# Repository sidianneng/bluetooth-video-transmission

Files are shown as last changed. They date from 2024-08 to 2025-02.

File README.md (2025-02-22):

# 蓝牙图像传输 | [Ble video transmission](./README-EN.md)
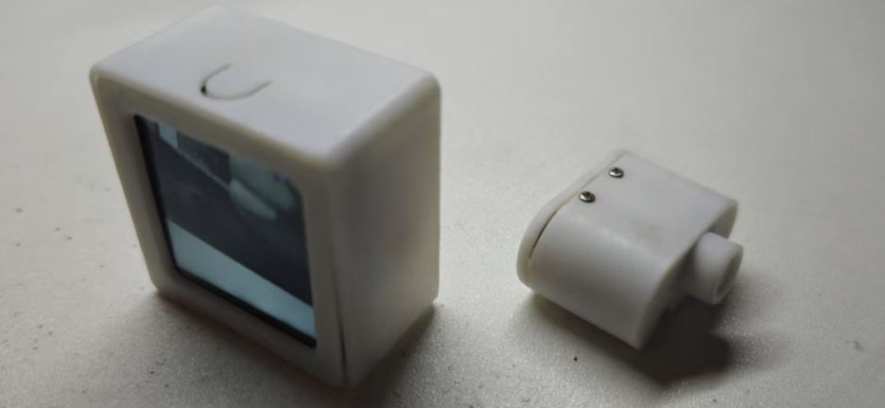
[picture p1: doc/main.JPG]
ble_video_tranmission


## 1 项目概述
现实应用中，无线视频传输一般使用的是带宽比较大的WIFI来实现，那么对于带宽非常有限的蓝牙来说是否有传输视频的可能性。其实23年上市的insta 360 go3已经给了我们答案：这个想法是可行的。
受insta 360 go3的启发，我开始了这个项目。本项目基于ESP32-S3实现。传输图像分辨率为240x240。

## 2 功能介绍
### 2.1 发送端
* 系统启动后初始化摄像头和开启ble gatt server
* 按下按键后指示灯开始显示工作状态
* 指示灯有红绿蓝三种颜色，其中绿色表示电量高，蓝色表示电量中等，红色表示电量低
* 指示灯慢闪表示发送端蓝牙没有被连接，快闪表示已经被连接了
* 再次按下按键后关闭指示灯
* 发送端放到充电仓中后会常亮显示表示正在充电(此时无法通过按键熄灭)

### 2.2 接收端
* 系统启动后会初始化屏幕和自动搜索ble gatt server
* 搜索到server后会自动连接和接收图像数据
* 按下按键后会开启屏幕背光，显示画面
* 屏幕右上角有电池图标显示电量
* 接入充电线后电池图标会显示正在充电中

## 3 原理解析
* 蓝牙的传输基于GATT的NOTIFY实现，最大传输速度在90KB/s左右
* 摄像头使用的OV2640，在图像格式配置为JPEG，分辨率为240x240
* JPEG解码库使用的esp_jpeg

### 如果对本项目有任何疑问，欢迎在issue中与我讨论。

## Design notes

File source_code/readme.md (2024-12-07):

# Video data packet definition

* packet header 1byte
* current frame count 1byte
* current total packet count 1bytes
* current current packet count 1bytes
* current packet length 2bytes
* packet data nbytes

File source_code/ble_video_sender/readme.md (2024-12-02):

# How to build this code

`idf.py set-target esp32s3`

`idf.py add-dependency "espressif/esp32-camera"`

`idf.py build`

`idf.py -p /dev/ttyxxx flash monitor`

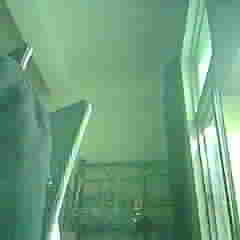
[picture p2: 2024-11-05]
source_code/ble_video_receiver/main/image.jpg

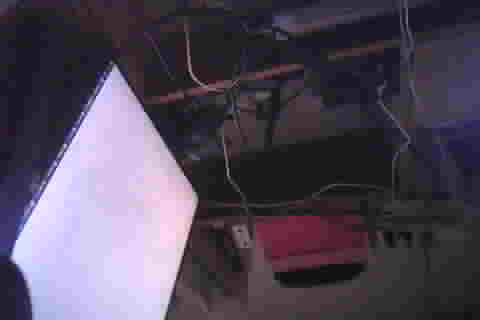
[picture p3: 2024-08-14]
tools/output.jpg

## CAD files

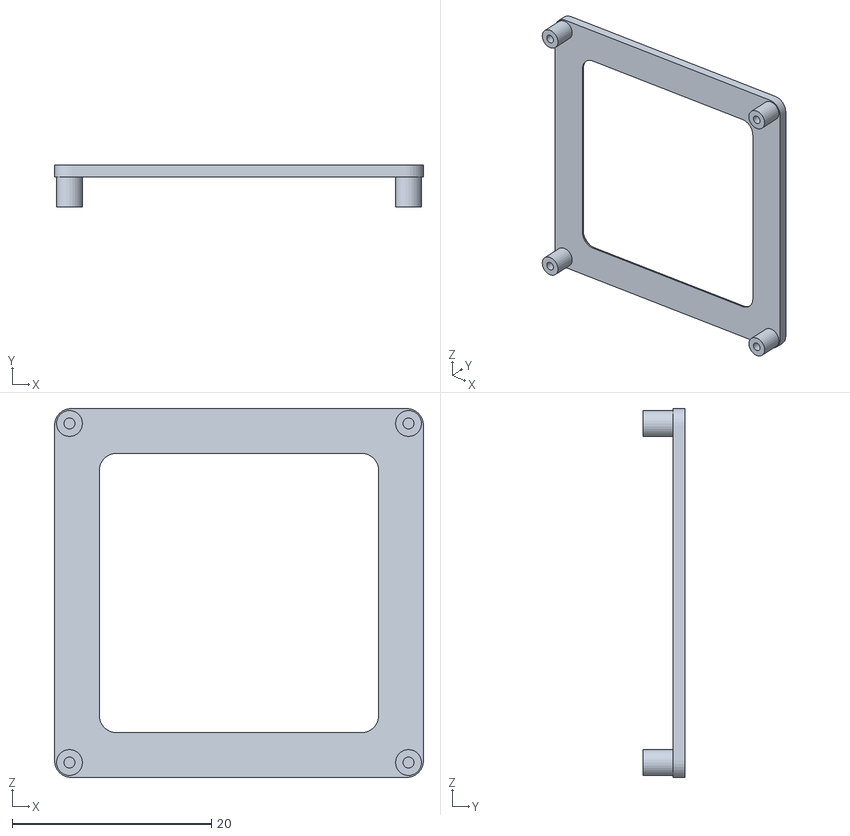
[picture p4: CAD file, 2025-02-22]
3d-modules/receiver-v7.stl
37.0 x 4.20 x 37.0

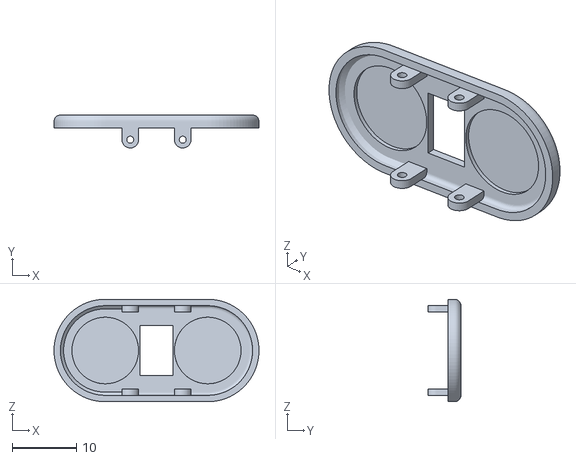
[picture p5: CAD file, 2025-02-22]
3d-modules/sender-back-v22.stl
32.0 x 5.14 x 16.0

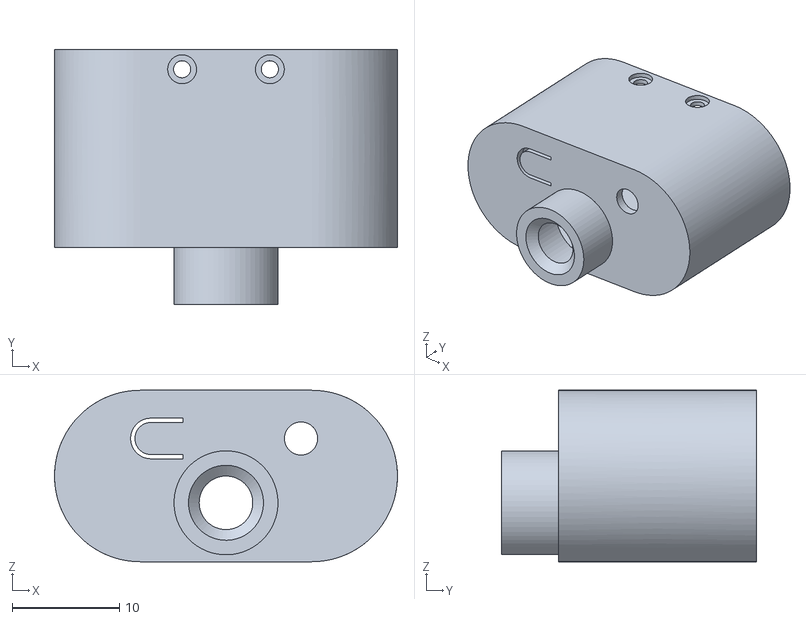
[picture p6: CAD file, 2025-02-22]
3d-modules/sender-new-v19.stl
32.0 x 23.8 x 16.0

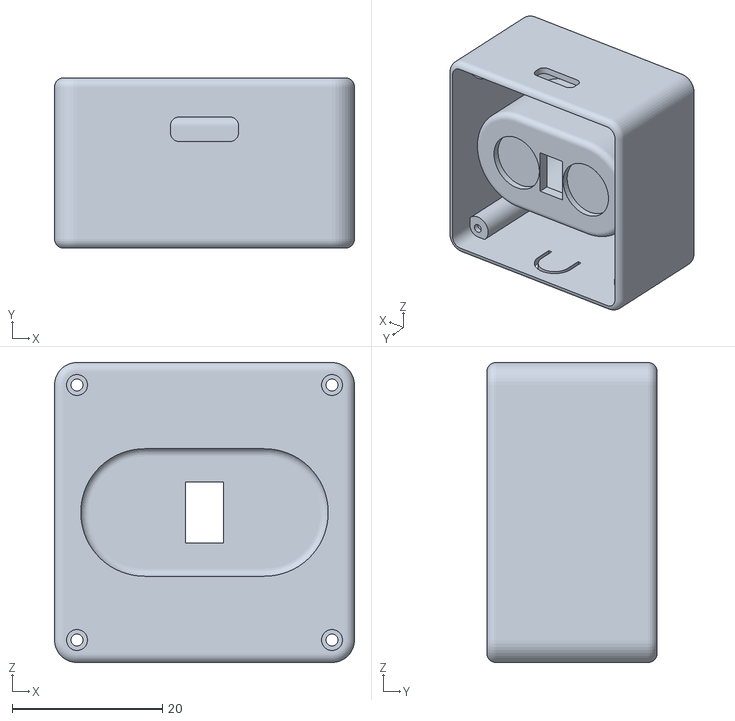
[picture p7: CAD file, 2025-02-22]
3d-modules/ble-video-camera-v88.stl
40.0 x 22.7 x 40.0

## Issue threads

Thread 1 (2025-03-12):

GATT写事件中出现0x85报错（ESP_GATTC_WRITE_DESCR_EVT）

LH-GO, 2025-03-12:
**报错log出现在ble_client.c文件的327行**
```
case ESP_GATTC_WRITE_DESCR_EVT:
        if (p_data->write.status != ESP_GATT_OK){
            ESP_LOGE(GATTC_TAG, "write descr failed, error status = %x", p_data->write.status);
            break;
        }
```

**Log出现错误时的部分信息，完整log请查看附件(108行)**

```
I (3095) GATTC_DEMO: Notify Bit rate = 0 Byte/s, = 0 bit/s
I (5095) GATTC_DEMO: Notify Bit rate = 0 Byte/s, = 0 bit/s
I (7095) GATTC_DEMO: Notify Bit rate = 0 Byte/s, = 0 bit/s
W (8755) BT_APPL: gattc_conn_cb: if=3 st=0 id=3 rsn=0x8
W (8755) BT_HCI: hcif disc complete: hdl 0x1, rsn 0x8
E (8755) GATTC_DEMO: write descr failed, error status = 85
```

**log附件**
[log_20250312.txt](https://github.com/user-attachments/files/19211943/log_20250312.txt)

sidianneng, 2025-03-12:
你好，首先根据esp-idf的[相关错误定义](https://github.com/espressif/esp-idf/blob/1f46216a7214e27c1e351b4310acf7fcd77029d4/components/bt/host/bluedroid/api/include/api/esp_gatt_defs.h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)，错误码85是GATT的通用错误。
通过分析你提供日志可以发现，你的GATT client已经发现并且连接到了GATT server，错误发生在连接完成后。
我这里有一下几个问题排查思路提供给你：
1 你提供的日志里面有`v5.4-dirty`，你本地使用过的esp-idf应该是被修改过的，你可以试试使用v5.4.0的未修改过的SDK进行固件编译和下载测试。
2 在我发布的最新的ble_client.c的代码中，日志`Notify Bit rate = `应该是被注释掉了才对，但是你提供的日志里面是出于开启的状态，所以麻烦拉取本仓库的最新代码后再重新编译下载固件试试。
3 如果方法1和2都尝试过后问题仍然存在，那么有可能是硬件电路的原因，按我之前调试的经验来看，要特别注意电源的供电能力，蓝牙连续通讯时耗电量是比较高的，如果供电不足，会出现运行过程中直接异常的问题。

希望以上思路对你排查问题原因有帮助。

LH-GO, 2025-03-16:
您好，打扰了
1.重新下载IDF_5.4，发现编译后还是有更改，使用git status检查本地更改文件，发现只是一些.sh文件变更，怀疑是编译后自动生成的（应该不是这个影响的）
2.我重新Clone了你的工程，不会出现以上问题，但是出现图片解码报错，暂时没找到问题原因

具体请查看附件Log

[log_20250316.txt](https://github.com/user-attachments/files/19271958/log_20250316.txt)

```
I (2528) GATTC_DEMO: ESP_GATTC_SEARCH_RES_EVT
I (2528) GATTC_DEMO: service found
I (2538) GATTC_DEMO: UUID16: ff
I (2538) GATTC_DEMO: ESP_GATTC_SEARCH_CMPL_EVT
I (2538) GATTC_DEMO: ESP_GATTC_REG_FOR_NOTIFY_EVT
I (2688) GATTC_DEMO: write descr success
I (3078) GATTC_DEMO: FPS:2
E (3138) JPEG: esp_jpeg_decode(97): Error in preparing JPEG image! 2
E (3168) JPEG: esp_jpeg_decode(97): Error in preparing JPEG image! 2
E (3198) JPEG: esp_jpeg_decode(97): Error in preparing JPEG image! 2
```

LH-GO, 2025-03-20:
感谢回复，问题已关闭

Closed 2025-03-20.

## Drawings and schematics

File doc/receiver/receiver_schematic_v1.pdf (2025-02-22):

5

4

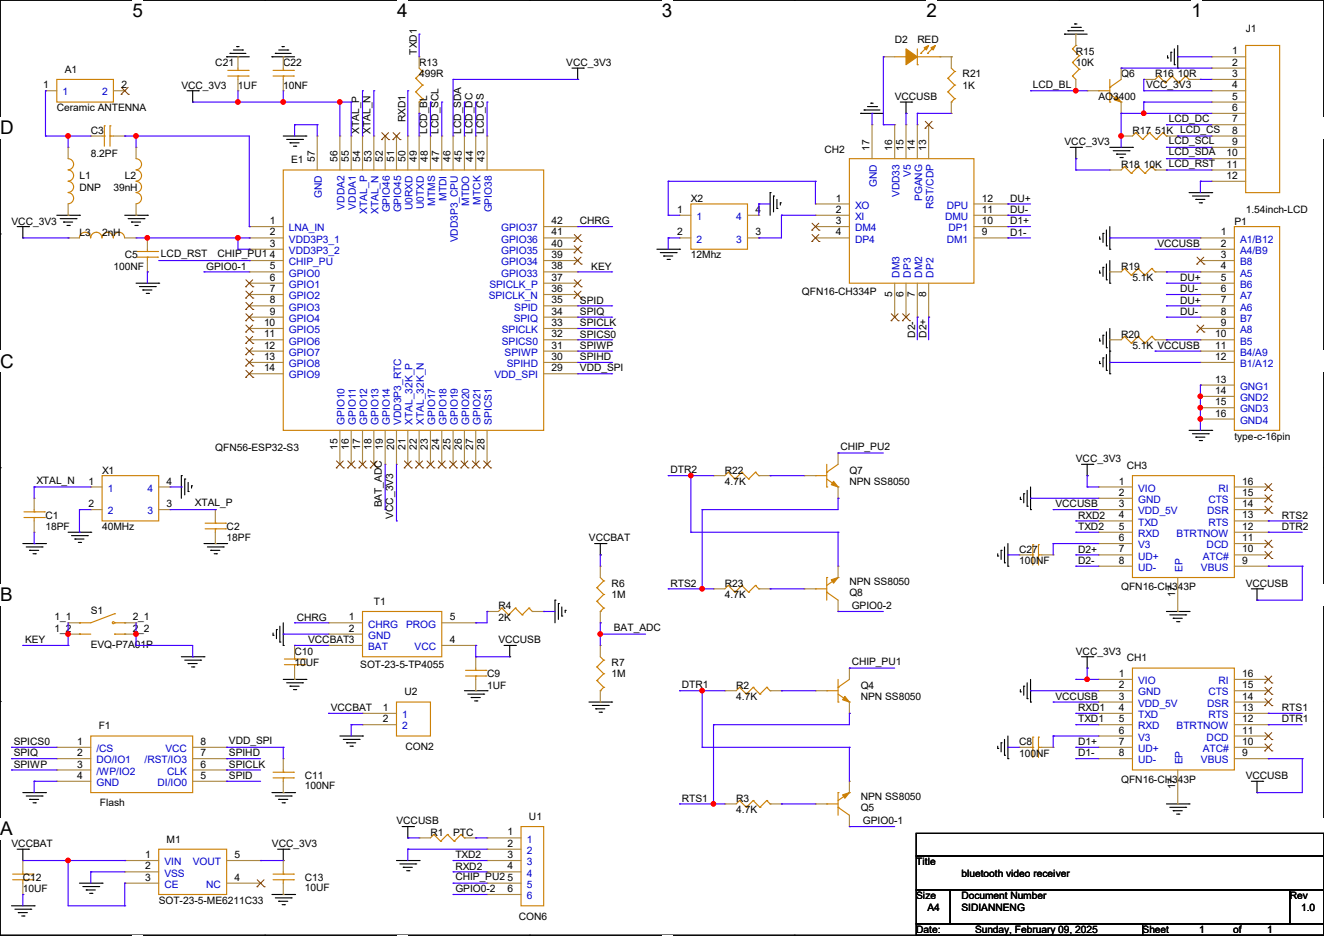
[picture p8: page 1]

8 DM1 9 DP1 10 DMU 11 DPU 12 RST/CDP 13 PGANG 14 V5 15 VDD33 16 GND 17

VDD_SPI 29 SPIHD 30 SPIWP 31 SPICS0 32 SPICLK 33 SPIQ 34 SPID 35 SPICLK_N 36 SPICLK_P 37 GPIO33 38 GPIO34 39 GPIO35 40 GPIO36 41 GPIO37 42 GPIO³⁸ ⁴³ MTCK ⁴⁴ MTDO ⁴⁵ VDD³P³_CPU ⁴⁶ MTDI 47 MTMS ⁴⁸ U⁰TXD ⁴⁹ U⁰RXD ⁵⁰ GPIO⁴⁵ ⁵¹ GPIO⁴⁶ ⁵² XTAL_N ⁵³ XTAL_P ⁵⁴ VDDA¹ ⁵⁵ VDDA² ⁵⁶ GND ⁵⁷

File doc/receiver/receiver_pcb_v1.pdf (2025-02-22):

# Q8R19 R1

# CH3R15 X2 Q7

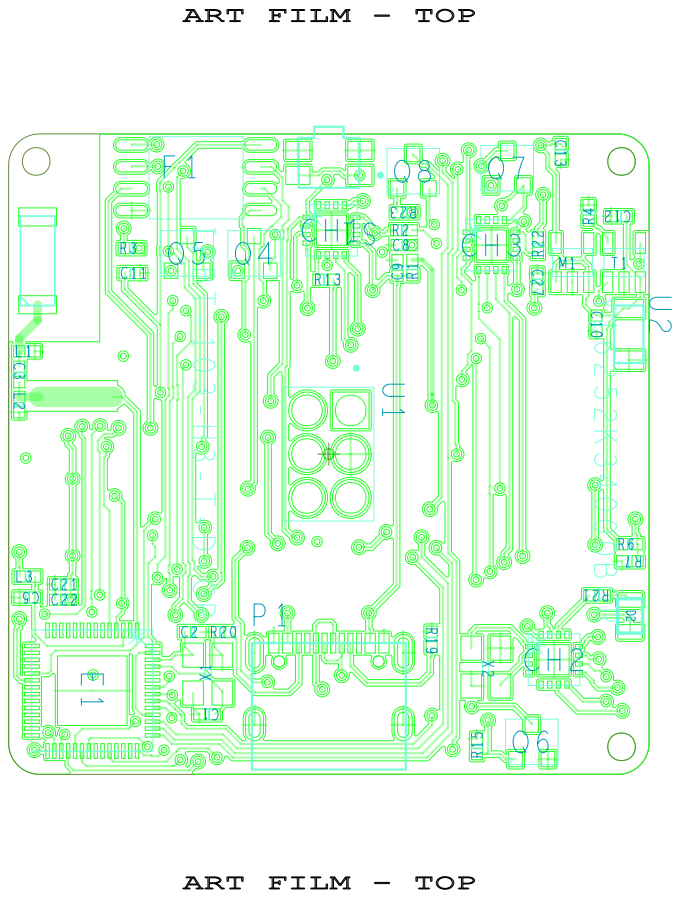
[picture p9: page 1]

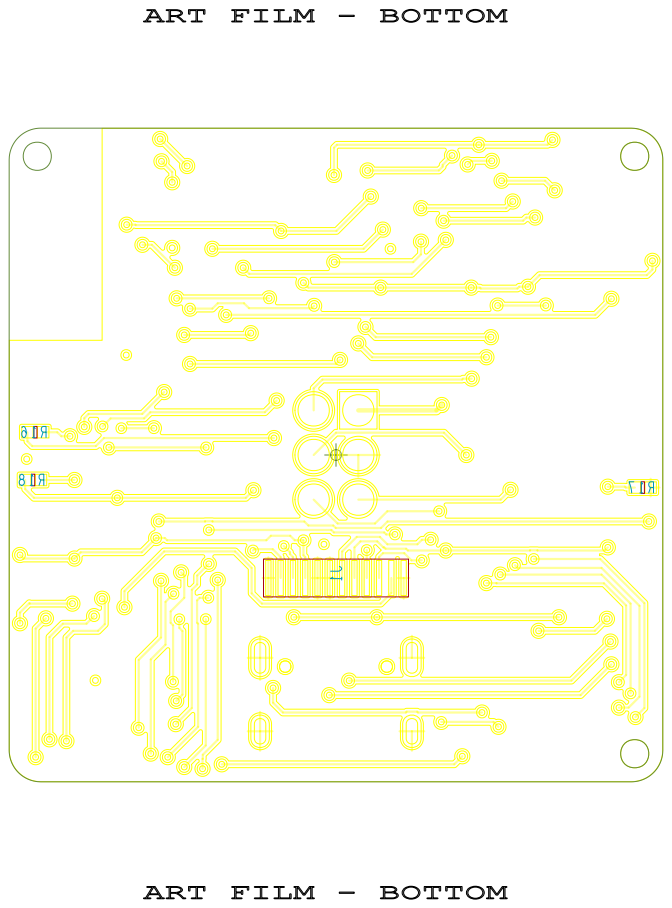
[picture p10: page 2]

ART FILM - BOTTOM

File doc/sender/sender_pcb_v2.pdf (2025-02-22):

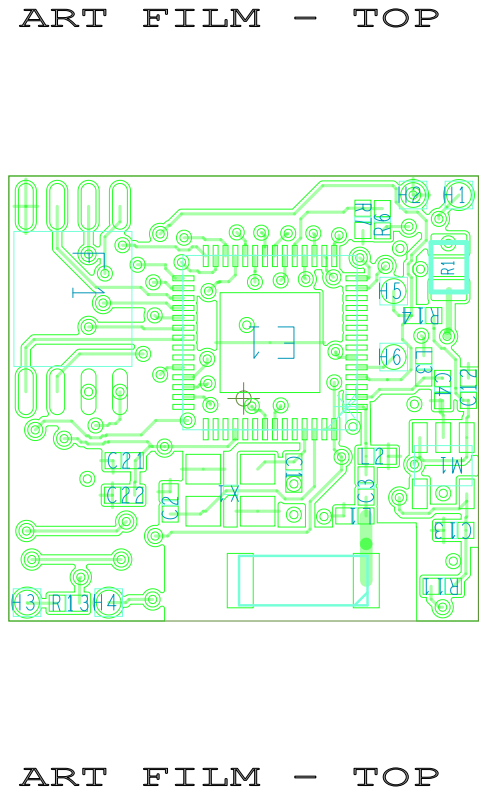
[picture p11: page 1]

ART FILM - TOP

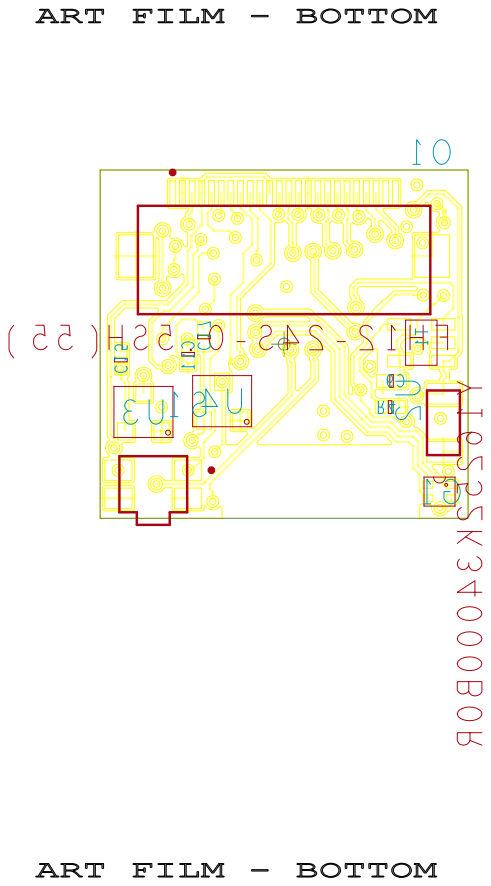
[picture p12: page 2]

ART FILM - BOTTOM

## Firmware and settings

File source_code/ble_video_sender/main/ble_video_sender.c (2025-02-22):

/*
 * SPDX-FileCopyrightText: 2021-2023 Espressif Systems (Shanghai) CO LTD
 *
 * SPDX-License-Identifier: Unlicense OR CC0-1.0
 */

/****************************************************************************
*
* This is the demo to test the BLE throughput. It should be used together with throughput_client demo.
*
****************************************************************************/

#include <stdio.h>
#include <stdlib.h>
#include <string.h>
#include <inttypes.h>
#include "freertos/FreeRTOS.h"
#include "freertos/task.h"
#include "freertos/event_groups.h"
#include "freertos/semphr.h"

#include "esp_system.h"
#include "esp_log.h"
#include "nvs_flash.h"
#include "esp_bt.h"
#include "esp_gap_ble_api.h"
#include "esp_gatts_api.h"
#include "esp_bt_defs.h"
#include "esp_bt_main.h"
#include "esp_bt_device.h"
#include "esp_gatt_common_api.h"
#include "esp_timer.h"

#include "sdkconfig.h"
#include "pic_packet.h"
#include "key_input.h"
#include "battery.h"

#define GATTS_TAG "GATTS_DEMO"

extern QueueHandle_t gpio_evt_queue;

#define LED_RED     34
#define LED_GREEN   36
#define LED_BLUE    35

//camera include
#include <nvs_flash.h>
#include "esp_camera.h"

#define CAM_PIN_PWDN -1  //power down is not used
#define CAM_PIN_RESET -1 //software reset will be performed
#define CAM_PIN_XCLK 17
#define CAM_PIN_SIOD 26 
#define CAM_PIN_SIOC 21 

#define CAM_PIN_D7 18
#define CAM_PIN_D6 16
#define CAM_PIN_D5 15
#define CAM_PIN_D4 12
#define CAM_PIN_D3 10
#define CAM_PIN_D2 8
#define CAM_PIN_D1 9
#define CAM_PIN_D0 11
#define CAM_PIN_VSYNC 20
#define CAM_PIN_HREF 19
#define CAM_PIN_PCLK 13

static camera_config_t camera_config = {
    .pin_pwdn = CAM_PIN_PWDN,
    .pin_reset = CAM_PIN_RESET,
    .pin_xclk = CAM_PIN_XCLK,
    .pin_sccb_sda = CAM_PIN_SIOD,
    .pin_sccb_scl = CAM_PIN_SIOC,

    .pin_d7 = CAM_PIN_D7,
    .pin_d6 = CAM_PIN_D6,
    .pin_d5 = CAM_PIN_D5,
    .pin_d4 = CAM_PIN_D4,
    .pin_d3 = CAM_PIN_D3,
    .pin_d2 = CAM_PIN_D2,
    .pin_d1 = CAM_PIN_D1,
    .pin_d0 = CAM_PIN_D0,
    .pin_vsync = CAM_PIN_VSYNC,
    .pin_href = CAM_PIN_HREF,
    .pin_pclk = CAM_PIN_PCLK,

    //XCLK 20MHz or 10MHz for OV2640 double FPS (Experimental)
    .xclk_freq_hz = 20000000,
    .ledc_timer = LEDC_TIMER_0,
    .ledc_channel = LEDC_CHANNEL_0,

    .pixel_format = PIXFORMAT_JPEG,
    .frame_size = FRAMESIZE_240X240,

    .jpeg_quality = 50, //0-63, for OV series camera sensors, lower number means higher quality
    .fb_count = 1,       //When jpeg mode is used, if fb_count more than one, the driver will work in continuous mode.
    .fb_location = CAMERA_FB_IN_DRAM,
    .grab_mode = CAMERA_GRAB_WHEN_EMPTY,
};

static esp_err_t init_camera(void)
{
    //initialize the camera
    esp_err_t err = esp_camera_init(&camera_config);
    if (err != ESP_OK)
    {
        ESP_LOGE(GATTS_TAG, "Camera Init Failed");
        return err;
    }

    return ESP_OK;
}

/**********************************************************
 * picture packet
 **********************************************************/
#define NOTIFY_LEN    495
Pic_Packet pic_packet;
static uint8_t packetdata[NOTIFY_LEN] = {0};

/**********************************************************
 * Thread/Task reference
 **********************************************************/
#ifdef CONFIG_BLUEDROID_PINNED_TO_CORE
#define BLUETOOTH_TASK_PINNED_TO_CORE              (CONFIG_BLUEDROID_PINNED_TO_CORE < CONFIG_FREERTOS_NUMBER_OF_CORES ? CONFIG_BLUEDROID_PINNED_TO_CORE : tskNO_AFFINITY)
#else
#define BLUETOOTH_TASK_PINNED_TO_CORE              (0)
#endif

#define SECOND_TO_USECOND          1000000


#if (CONFIG_EXAMPLE_GATTS_NOTIFY_THROUGHPUT)
#define GATTS_NOTIFY_LEN    495
static SemaphoreHandle_t gatts_semaphore;
static bool can_send_notify = false;
static uint8_t indicate_data[GATTS_NOTIFY_LEN] = {0x01, 0x02, 0x03, 0x04, 0x05, 0x06, 0x07, 0x08, 0x09, 0x0a};

//jpg picture data
static uint8_t jpeg_pic[] = 
{0xff,0xd8,0xff,0xe0,0x00,0x10,0x4a,0x46,0x49,0x46,0x00,0x01,0x01,0x01,0x00,0x00,0x00,0x00,0x00,0x00,0xff,0xdb,0x00,0x43,0x00,0x32,0x22,0x26,0x2c,0x26,0x1f,0x32,0x2c,0x29,0x2c,0x38,0x35,0x32,0x3b,0x4b,0x7d,0x51,0x4b,0x45,0x45,0x4b,0x99,0x6d,0x74,0x5b,0x7d,0xb5,0x9f,0xbf,0xbc,0xb2,0x9f,0xaf,0xac,0xc8,0xe1,0xff,0xf4,0xc8,0xd5,0xff,0xd8,0xac,0xaf,0xfa,0xff,0xfd,0xff,0xff,0xff,0xff,0xff,0xff,0xc2,0xf1,0xff,0xff,0xff,0xff,0xff,0xff,0xff,0xff,0xff,0xff,0xdb,0x00,0x43,0x01,0x35,0x38,0x38,0x4b,0x42,0x4b,0x93,0x51,0x51,0x93,0xff,0xce,0xaf,0xce,0xff,0xff,0xff,0xff,0xff,0xff,0xff,0xff,0xff,0xff,0xff,0xff,0xff,0xff,0xff,0xff,0xff,0xff,0xff,0xff,0xff,0xff,0xff,0xff,0xff,0xff,0xff,0xff,0xff,0xff,0xff,0xff,0xff,0xff,0xff,0xff,0xff,0xff,0xff,0xff,0xff,0xff,0xff,0xff,0xff,0xff,0xff,0xff,0xff,0xff,0xff,0xc4,0x00,0x1f,0x00,0x00,0x01,0x05,0x01,0x01,0x01,0x01,0x01,0x01,0x00,0x00,0x00,0x00,0x00,0x00,0x00,0x00,0x01,0x02,0x03,0x04,0x05,0x06,0x07,0x08,0x09,0x0a,0x0b,0xff,0xc4,0x00,0xb5,0x10,0x00,0x02,0x01,0x03,0x03,0x02,0x04,0x03,0x05,0x05,0x04,0x04,0x00,0x00,0x01,0x7d,0x01,0x02,0x03,0x00,0x04,0x11,0x05,0x12,0x21,0x31,0x41,0x06,0x13,0x51,0x61,0x07,0x22,0x71,0x14,0x32,0x81,0x91,0xa1,0x08,0x23,0x42,0xb1,0xc1,0x15,0x52,0xd1,0xf0,0x24,0x33,0x62,0x72,0x82,0x09,0x0a,0x16,0x17,0x18,0x19,0x1a,0x25,0x26,0x27,0x28,0x29,0x2a,0x34,0x35,0x36,0x37,0x38,0x39,0x3a,0x43,0x44,0x45,0x46,0x47,0x48,0x49,0x4a,0x53,0x54,0x55,0x56,0x57,0x58,0x59,0x5a,0x63,0x64,0x65,0x66,0x67,0x68,0x69,0x6a,0x73,0x74,0x75,0x76,0x77,0x78,0x79,0x7a,0x83,0x84,0x85,0x86,0x87,0x88,0x89,0x8a,0x92,0x93,0x94,0x95,0x96,0x97,0x98,0x99,0x9a,0xa2,0xa3,0xa4,0xa5,0xa6,0xa7,0xa8,0xa9,0xaa,0xb2,0xb3,0xb4,0xb5,0xb6,0xb7,0xb8,0xb9,0xba,0xc2,0xc3,0xc4,0xc5,0xc6,0xc7,0xc8,0xc9,0xca,0xd2,0xd3,0xd4,0xd5,0xd6,0xd7,0xd8,0xd9,0xda,0xe1,0xe2,0xe3,0xe4,0xe5,0xe6,0xe7,0xe8,0xe9,0xea,0xf1,0xf2,0xf3,0xf4,0xf5,0xf6,0xf7,0xf8,0xf9,0xfa,0xff,0xc4,0x00,0x1f,0x01,0x00,0x03,0x01,0x01,0x01,0x01,0x01,0x01,0x01,0x01,0x01,0x00,0x00,0x00,0x00,0x00,0x00,0x01,0x02,0x03,0x04,0x05,0x06,0x07,0x08,0x09,0x0a,0x0b,0xff,0xc4,0x00,0xb5,0x11,0x00,0x02,0x01,0x02,0x04,0x04,0x03,0x04,0x07,0x05,0x04,0x04,0x00,0x01,0x02,0x77,0x00,0x01,0x02,0x03,0x11,0x04,0x05,0x21,0x31,0x06,0x12,0x41,0x51,0x07,0x61,0x71,0x13,0x22,0x32,0x81,0x08,0x14,0x42,0x91,0xa1,0xb1,0xc1,0x09,0x23,0x33,0x52,0xf0,0x15,0x62,0x72,0xd1,0x0a,0x16,0x24,0x34,0xe1,0x25,0xf1,0x17,0x18,0x19,0x1a,0x26,0x27,0x28,0x29,0x2a,0x35,0x36,0x37,0x38,0x39,0x3a,0x43,0x44,0x45,0x46,0x47,0x48,0x49,0x4a,0x53,0x54,0x55,0x56,0x57,0x58,0x59,0x5a,0x63,0x64,0x65,0x66,0x67,0x68,0x69,0x6a,0x73,0x74,0x75,0x76,0x77,0x78,0x79,0x7a,0x82,0x83,0x84,0x85,0x86,0x87,0x88,0x89,0x8a,0x92,0x93,0x94,0x95,0x96,0x97,0x98,0x99,0x9a,0xa2,0xa3,0xa4,0xa5,0xa6,0xa7,0xa8,0xa9,0xaa,0xb2,0xb3,0xb4,0xb5,0xb6,0xb7,0xb8,0xb9,0xba,0xc2,0xc3,0xc4,0xc5,0xc6,0xc7,0xc8,0xc9,0xca,0xd2,0xd3,0xd4,0xd5,0xd6,0xd7,0xd8,0xd9,0xda,0xe2,0xe3,0xe4,0xe5,0xe6,0xe7,0xe8,0xe9,0xea,0xf2,0xf3,0xf4,0xf5,0xf6,0xf7,0xf8,0xf9,0xfa,0xff,0xc0,0x00,0x11,0x08,0x00,0xf0,0x00,0xf0,0x03,0x01,0x21,0x00,0x02,0x11,0x01,0x03,0x11,0x01,0xff,0xda,0x00,0x0c,0x03,0x01,0x00,0x02,0x11,0x03,0x11,0x00,0x3f,0x00,0x45,0xe1,0xaa,0x6a,0x92,0x02,0x96,0x98,0x0a,0x29,0x69,0x08,0x4a,0x28,0x18,0x94,0x50,0x01,0x49,0x4c,0x41,0x49,0x40,0xc2,0x92,0x80,0x12,0x92,0x80,0x12,0x8a,0x00,0x4a,0x29,0x80,0x53,0xe1,0x1f,0x39,0xfa,0x50,0x22,0x59,0x3a,0x53,0x25,0xa4,0x04,0x74,0x62,0x98,0x06,0x29,0x68,0x02,0x3a,0x96,0x33,0x95,0xa4,0x31,0xf4,0xb4,0x80,0x5a,0x5a,0x04,0x25,0x14,0x0c,0x29,0x28,0x00,0xa4,0xa0,0x02,0x92,0x98,0x05,0x25,0x00,0x14,0x94,0x00,0x94,0x94,0x00,0x51,0x4c,0x41,0x52,0xdb,0xf4,0x63,0x48,0x07,0x3f,0xde,0x14,0x84,0x67,0x77,0xd2,0x80,0x21,0xa7,0x53,0x00,0xa2,0x80,0x23,0xa5,0x43,0x86,0xa4,0x51,0x35,0x2d,0x21,0x05,0x3a,0x80,0x0a,0x4a,0x00,0x29,0x28,0x00,0xa4,0xa0,0x02,0x92,0x80,0x0a,0x4a,0x60,0x25,0x25,0x00,0x14,0x94,0x00,0x51,0x40,0x05,0x4f,0x07,0xdc,0xa0,0x42,0xff,0x00,0xcb,0x4f,0xc2,0x84,0xe7,0x3e,0xe6,0x80,0x20,0x14,0xb4,0xc0,0x5a,0x28,0x02,0x3a,0x4a,0x91,0x92,0xa1,0xc8,0xa7,0xd0,0x01,0x4a,0x28,0x01,0x69,0x28,0x00,0xa4,0xa0,0x02,0x92,0x80,0x0a,0x4a,0x00,0x29,0x29,0x80,0x94,0x50,0x02,0x52,0x50,0x01,0x45,0x00,0x15,0x66,0x2f,0xf5,0x62,0x81,0x0d,0xfe,0xf9,0xa7,0x27,0x0a,0x28,0x11,0x0b,0x70,0xe6,0x8a,0x63,0x0a,0x5a,0x00,0x8e,0x9b,0x52,0x31,0xc8,0x7e,0x6a,0x96,0x80,0x16,0x96,0x80,0x16,0x92,0x80,0x0a,0x4a,0x00,0x29,0x28,0x00,0xa4,0xa6,0x01,0x49,0x40,0x09,0x49,0x40,0x09,0x45,0x00,0x14,0x50,0x01,0x57,0x31,0xb5,0x71,0xe9,0x40,0x88,0x4f,0x29,0xf5,0xa9,0x68,0x02,0x29,0x7f,0xd6,0x53,0x69,0x80,0x52,0xd0,0x04,0x54,0x52,0x18,0xda,0x92,0x36,0x2c,0x39,0xfa,0x50,0x04,0x94,0xb4,0x80,0x5a,0x28,0x01,0x29,0x28,0x00,0xa4,0xa0,0x04,0xa2,0x80,0x12,0x8a,0x00,0x4a,0x4a,0x60,0x25,0x14,0x00,0x51,0x40,0x0a,0x9f,0x7c,0x7d,0x6a,0xd3,0xf4,0x34,0x08,0x8b,0xfb,0xa2,0xa6,0x5a,0x42,0x23,0xb9,0xfb,0xeb,0xf4,0xa8,0xea,0x86,0x2d,0x2d,0x00,0x41,0x4c,0x2f,0x9e,0x94,0x86,0x20,0xab,0xb6,0xc9,0xb4,0x73,0xd1,0x39,0xfc,0x68,0x01,0xbd,0x79,0xf5,0xa2,0x90,0x0b,0x4b,0x40,0x0d,0xa2,0x80,0x12,0x8a,0x00,0x4a,0x28,0x01,0x28,0xa0,0x04,0xa4,0xa6,0x02,0x51,0x40,0x05,0x14,0xc4,0x3e,0x1f,0xf5,0x82,0xa6,0x93,0xee,0xd2,0x01,0xa3,0xef,0x55,0x88,0xc5,0x21,0x11,0x5d,0xfd,0xe4,0xa8,0xaa,0x86,0x2d,0x39,0x7a,0xd0,0x05,0x45,0xcd,0x38,0xae,0x7d,0xa8,0x01,0x22,0x5f,0x9f,0x9e,0xdc,0xd5,0x8b,0x83,0xb6,0x35,0x8b,0xb9,0xe5,0xa8,0x28,0x6a,0x9c,0x8a,0x75,0x48,0x85,0xa5,0xa0,0x06,0xd2,0x50,0x01,0x49,0x40,0x05,0x14,0x00,0x94,0x94,0x00,0x52,0x53,0x01,0x28,0xa0,0x02,0x90,0x9a,0x04,0x49,0x6f,0xf7,0xaa,0x47,0xa0,0x04,0x4e,0xb5,0x71,0x06,0x05,0x00,0x55,0x9f,0x99,0xcf,0xb7,0x14,0xca,0x63,0x16,0x9e,0x28,0x11,0x4c,0x53,0xe8,0x01,0xc8,0x70,0xe3,0x3d,0x3b,0xd1,0x2b,0x6f,0x94,0xb5,0x22,0x86,0xa9,0xc1,0xa9,0x69,0x08,0x5a,0x5a,0x00,0x43,0x49,0x40,0x05,0x25,0x00,0x14,0x94,0x00,0x52,0x50,0x01,0x49,0x4c,0x04,0xa2,0x80,0x06,0xa6,0xd3,0x11,0x2d,0xbf,0xfa,0xcf,0xc2,0xa5,0x7a,0x40,0x11,0x7f,0xad,0x15,0x72,0x82,0x91,0x9f,0x9d,0xcc,0x5b,0xd4,0xd3,0xa9,0x92,0x2d,0x3e,0x90,0xca,0x62,0x9d,0x4c,0x03,0xb5,0x14,0x80,0x4a,0x91,0x0e,0x56,0x90,0x0e,0xa5,0xa0,0x00,0xd2,0x50,0x01,0x45,0x00,0x25,0x14,0x00,0x94,0x50,0x02,0x52,0x50,0x01,0x45,0x30,0x1a,0xd4,0x94,0xc4,0x49,0x07,0xfa,0xe5,0xab,0x12,0x54,0x80,0x89,0xfe,0xb0,0x54,0xd7,0x07,0x10,0xb7,0xbf,0x14,0xd0,0xca,0x9d,0xe9,0xd4,0xc4,0x28,0xa7,0x52,0x19,0x56,0x93,0x75,0x30,0x01,0xcd,0x3f,0xbf,0xd6,0x80,0x12,0x84,0xe0,0xd4,0x8c,0x96,0x8a,0x04,0x2d,0x14,0x00,0x94,0x52,0x00,0xa4,0xa6,0x01,0x49,0x40,0x05,0x25,0x00,0x14,0x94,0x00,0x8d,0x4d,0xaa,0x10,0xf8,0xcf,0xce,0xbf,0x5a,0xb7,0x2f,0x4a,0x90,0x18,0x3e,0xf8,0xa5,0xbb,0x6e,0x55,0x3f,0x1a,0x68,0x64,0x34,0xea,0x04,0x3a,0x96,0x81,0x94,0x8d,0x36,0x98,0x87,0x21,0xa9,0x16,0x81,0x87,0xb5,0x18,0xa4,0x03,0xd7,0xa5,0x3a,0x90,0xc2,0x96,0x81,0x05,0x14,0x80,0x4a,0x29,0x80,0x52,0x50,0x02,0x51,0x40,0x09,0x49,0x40,0x08,0xf4,0x95,0x42,0x01,0x57,0xe5,0xe5,0x0d,0x48,0x11,0x0f,0xe1,0xa6,0x4a,0x77,0x4c,0x7f,0x2a,0x60,0x27,0x57,0xc7,0xb5,0x38,0xfd,0xef,0xc3,0x34,0xc0,0x29,0x69,0x0c,0xa3,0x49,0x4c,0x43,0x96,0xa6,0x5a,0x06,0x21,0x38,0x6a,0x7d,0x20,0x14,0x52,0xd4,0x80,0xb4,0x85,0x80,0xef,0x4c,0x06,0xac,0x99,0x3d,0x29,0xf4,0x00,0x94,0x50,0x02,0x51,0x40,0x09,0x49,0x40,0x09,0x45,0x30,0x1a,0xdd,0x69,0x29,0x88,0x5a,0xbf,0xd6,0x21,0xf4,0xa9,0x02,0x20,0x71,0x10,0x3e,0x95,0x12,0x50,0x03,0xa3,0xff,0x00,0x5a,0xb4,0xff,0x00,0xe2,0x5f,0xa5,0x30,0x1d,0x45,0x21,0x99,0x94,0xea,0xa0,0x1e,0xb5,0x28,0xa0,0x06,0x3f,0x5a,0x7a,0x1a,0x00,0x7d,0x33,0xcc,0xf4,0xe6,0xa4,0x06,0x97,0x63,0x4d,0xaa,0x10,0xe4,0x19,0x6c,0x55,0x99,0x47,0x29,0xf4,0xa4,0x32,0x3a,0x29,0x00,0x94,0x50,0x02,0x52,0x50,0x02,0x51,0x40,0x08,0xd4,0xda,0x62,0x14,0x75,0xab,0xb1,0x7f,0xa8,0x5a,0x00,0x8d,0xbf,0xd4,0x7f,0xc0,0xb1,0x4c,0xfe,0x1a,0x00,0x5e,0x9b,0x0f,0xbd,0x4c,0xe3,0xe7,0x1f,0x5a,0x00,0x5a,0x4a,0x91,0x99,0xb4,0x55,0x88,0x78,0xa7,0xad,0x03,0x12,0x5e,0xb4,0xa9,0xd2,0x80,0x10,0xf5,0xa2,0x80,0x12,0x96,0x90,0x89,0xad,0x53,0x2c,0x4d,0x3e,0x43,0xb9,0xcd,0x03,0x1b,0x49,0x48,0x02,0x92,0x80,0x12,0x8a,0x00,0x4a,0x4a,0x00,0x6b,0xd2,0x53,0x10,0x55,0xc8,0x3f,0xd5,0x7e,0x34,0x98,0x10,0xbf,0xdf,0xc5,0x1d,0x4d,0x00,0x2c,0x9c,0xab,0x63,0xb0,0xcd,0x4d,0x21,0xe3,0x3f,0x43,0x4c,0x64,0x84,0x52,0x54,0x01,0x97,0x4b,0x5a,0x08,0x5a,0x91,0x68,0x18,0xaf,0xf7,0x69,0x13,0xae,0x28,0x00,0x6f,0xbd,0x49,0x40,0x82,0x8a,0x40,0x5c,0x88,0x79,0x50,0xd4,0x55,0x23,0x0a,0x4a,0x00,0x29,0x29,0x80,0x94,0x94,0x00,0x52,0x50,0x02,0x35,0x32,0x98,0x82,0xac,0xc5,0xf7,0x4d,0x00,0x30,0x8f,0x9a,0x9c,0x83,0x9a,0x06,0x4d,0xe5,0x91,0x13,0x71,0xd6,0x99,0xd6,0xd9,0x7f,0xdd,0xc5,0x00,0x59,0x5f,0x99,0x41,0xa3,0x15,0x00,0x64,0x51,0x5a,0x08,0x70,0xa9,0x16,0x80,0x1d,0x4d,0xef,0x40,0xc1,0xba,0xd2,0x52,0x00,0xa5,0x8c,0x6e,0x7a,0x42,0x2e,0x4d,0xc6,0x17,0xf1,0xa8,0x68,0x18,0x52,0x52,0x00,0xa4,0xa6,0x02,0x52,0x50,0x01,0x4d,0xa0,0x04,0x6e,0x94,0xca,0x62,0x16,0xa7,0x87,0xd2,0x81,0x8f,0x61,0xf3,0x2f,0xd6,0xa5,0x81,0x76,0xbb,0x67,0xad,0x03,0x45,0x8a,0xa9,0x1f,0xfa,0xa2,0xbe,0x8f,0x4c,0x19,0x35,0xbf,0xfa,0x91,0x52,0xd4,0x58,0x2c,0x62,0x52,0xd5,0x88,0x72,0xd4,0x82,0x90,0x0b,0x40,0xa6,0x01,0x27,0x6a,0x6d,0x21,0x05,0x4f,0x6a,0xbd,0xe9,0x30,0x1e,0xe7,0x73,0x93,0x4c,0xa4,0x30,0xa4,0xa0,0x02,0x92,0x98,0x09,0x49,0x40,0x09,0x49,0x40,0x01,0xe9,0x51,0xd3,0x00,0xab,0x16,0xdf,0xeb,0x97,0xe9,0x40,0x16,0x25,0x4d,0xbb,0x4f,0xfb,0x42,0x9e,0x7f,0xe3,0xe5,0x3d,0x0a,0x9a,0x0a,0x24,0x35,0x5c,0x7f,0xac,0x9c,0x7d,0x1a,0x81,0x0f,0x83,0xa3,0x0f,0x7a,0x9a,0x98,0xd1,0x8b,0x45,0x04,0x8e,0x15,0x25,0x02,0x0a,0x70,0xa0,0x62,0x49,0xda,0x9b,0x48,0x42,0x55,0xd0,0x3c,0xb8,0xfe,0x82,0x80,0x22,0xa2,0xa4,0x62,0x51,0x40,0x09,0x49,0x4c,0x02,0x92,0x80,0x1b,0x45,0x00,0x07,0xa5,0x47,0x4c,0x41,0x53,0x41,0xfe,0xb1,0x3e,0xb4,0x0c,0xb7,0x78,0x7f,0x70,0x7d,0x7a,0xd2,0xcb,0xf7,0xe3,0x3e,0xf4,0xc6,0x48,0xfd,0x2a,0xbe,0x3f,0xd2,0xb1,0xfd,0xe4,0xa0,0x43,0xe0,0x3f,0x3b,0x7e,0x06,0xa7,0xa0,0xa4,0x62,0xd2,0xd0,0x48,0x2d,0x48,0x28,0x01,0x45,0x3e,0x80,0x18,0xfd,0x69,0x28,0x10,0xe8,0x97,0x7b,0x63,0xda,0xac,0xce,0xdf,0xaf,0x34,0x01,0x16,0xec,0xd1,0x52,0x31,0x28,0xa0,0x02,0x92,0x80,0x12,0x92,0x80,0x12,0x92,0x98,0x05,0x47,0x40,0x82,0xa5,0x43,0x8c,0x1f,0x4a,0x43,0x2e,0x5c,0x7c,0xca,0x47,0xb5,0x38,0x10,0xd6,0xe8,0xff,0x00,0x43,0x4c,0x09,0x1f,0xa5,0x55,0x6e,0x26,0x81,0xbe,0xa2,0x98,0x0f,0x8f,0x8b,0x8f,0xce,0xac,0xd0,0x52,0x31,0x69,0x68,0x20,0x51,0x52,0x52,0x00,0xa7,0x8a,0x63,0x18,0xdf,0x78,0xd3,0x7b,0xd2,0x11,0x62,0xd8,0x7f,0x17,0xb5,0x24,0xe7,0xe6,0x34,0x86,0x40,0x38,0x39,0xc5,0x3b,0x79,0xf4,0xa6,0x01,0xb8,0xd1,0xb9,0xbd,0x29,0x00,0x99,0x6a,0x32,0x68,0x01,0x32,0x69,0x33,0x4c,0x42,0x64,0xd1,0x48,0x02,0x92,0x98,0x05,0x3c,0x7d,0xd3,0x40,0x17,0xba,0xa0,0x34,0x90,0xff,0x00,0xc7,0xa1,0x1e,0x99,0x14,0x8a,0x26,0x3c,0xc7,0xf8,0x55,0x7b,0x8e,0x23,0x56,0xfe,0xeb,0x83,0x4c,0x42,0xb7,0xfa,0xf0,0x7d,0xea,0xd5,0x05,0x23,0x16,0x96,0x99,0x03,0x85,0x3a,0x81,0x8b,0x4e,0x14,0x08,0x6b,0xfd,0xe3,0x49,0xd5,0xa8,0x02,0xdc,0x7f,0x24,0x1f,0x41,0x55,0x9c,0xf6,0xef,0x52,0x31,0xab,0xd6,0x9d,0x8a,0x00,0x31,0x49,0xed,0x40,0x05,0x14,0x00,0x53,0x4d,0x00,0x27,0x02,0x92,0x81,0x06,0x45,0x36,0x98,0x05,0x3d,0x28,0x19,0x72,0x2f,0xf5,0x0b,0x4b,0x01,0xe2,0x41,0xef,0x40,0x0f,0x84,0xfe,0xe4,0x54,0x73,0xfc,0xd6,0xd2,0x0f,0x6a,0x60,0x24,0x8f,0x95,0x47,0xf5,0x5d,0xd5,0x72,0x91,0x48,0xc6,0xc5,0x14,0xc8,0x1c,0x29,0xc2,0x80,0x16,0x9d,0xda,0x80,0x1b,0x20,0x60,0x14,0xb7,0x7a,0x23,0x19,0x6f,0xc2,0x80,0x2d,0x5c,0x9c,0x28,0x5f,0x53,0x9a,0xaa,0xdf,0xeb,0x6a,0x46,0x1d,0x0f,0x14,0x64,0xfa,0x50,0x01,0x93,0x41,0xcd,0x00,0x02,0x93,0x9a,0x00,0x4a,0x4a,0x04,0x20,0xe9,0x4b,0x40,0x09,0x4d,0xa6,0x01,0x4e,0x4a,0x06,0x5c,0xb7,0xff,0x00,0x53,0xf4,0x34,0x91,0xff,0x00,0xac,0x90,0x7d,0x29,0x01,0x24,0x07,0xe4,0x23,0xde,0x86,0x19,0xdc,0xbe,0xa2,0xa8,0x08,0x53,0xe6,0xb4,0x53,0xf5,0x15,0x72,0x13,0xba,0x25,0x3e,0xd4,0x8a,0x32,0x68,0xa6,0x40,0xea,0x75,0x00,0x2d,0x0d,0xf7,0x29,0x0c,0x6e,0x72,0x7b,0x54,0xb6,0xc3,0x3f,0x8d,0x02,0x16,0xe1,0xbf,0xd2,0x4f,0xa0,0xe2,0xa3,0x1c,0xcd,0x40,0xc4,0x43,0x9c,0x9a,0x75,0x21,0x89,0xde,0x82,0x68,0x10,0x52,0x50,0x01,0x48,0x68,0x01,0xa3,0xa5,0x2d,0x30,0x12,0x98,0x7a,0xd0,0x02,0x53,0xd6,0x80,0x2d,0xda,0xfd,0xc7,0xfa,0xd2,0x7f,0xcb,0xcf,0xd5,0x4d,0x20,0x1f,0x0f,0xde,0x90,0x54,0x9f,0xc5,0x4c,0x08,0x22,0xcf,0x97,0x22,0xff,0x00,0x76,0x4a,0xb3,0x6b,0xfe,0xa7,0x1e,0x94,0x0d,0x19,0x74,0x53,0x24,0x70,0xa7,0x50,0x03,0xa8,0x7f,0xb9,0x40,0x11,0xd5,0xbb,0x7c,0x02,0x4f,0x65,0xa4,0x32,0xb9,0x24,0xb1,0x27,0xbd,0x22,0xfd,0xd9,0x28,0x01,0x14,0xe0,0x52,0xee,0xa0,0x03,0xbd,0x1d,0xa8,0x00,0x1d,0x28,0xa4,0x01,0x9a,0x43,0xd2,0x80,0x1a,0x29,0x73,0x40,0x09,0x9a,0x69,0xa6,0x03,0x69,0xe2,0x80,0x2c,0xdb,0x1f,0x9d,0x87,0xa8,0xa7,0x4b,0xc3,0xa9,0xf7,0xa4,0x02,0x42,0xc7,0xce,0xfa,0xad,0x4a,0x4f,0xf2,0xa6,0x04,0x79,0xc4,0xf3,0xaf,0xaa,0xee,0xa9,0xed,0x7f,0x8f,0xeb,0x40,0xcc,0xda,0x28,0x24,0x70,0xa7,0x53,0x01,0xd4,0x49,0xf7,0x68,0x01,0xab,0xf7,0xb3,0x56,0xbf,0xd5,0xda,0xfd,0x70,0x28,0x19,0x5b,0xf8,0x8d,0x37,0x3f,0x25,0x20,0x11,0x7a,0x53,0xa8,0x10,0x0a,0x4e,0x3b,0x8a,0x43,0x17,0xf8,0x69,0xbd,0xe8,0x10,0x0f,0xbe,0x29,0x58,0xf0,0xd4,0x14,0x32,0x8c,0xd0,0x21,0x3f,0x0a,0x43,0xf4,0xa0,0x04,0xa7,0x0a,0x60,0x58,0xb7,0xff,0x00,0x5c,0x2a,0x4b,0x8f,0xbb,0x9f,0x43,0x48,0x04,0xfb,0xb3,0x2d,0x4b,0x9c,0x30,0xa6,0x03,0x0e,0x3e,0xda,0xbc,0x7d,0xe5,0xc5,0x2d,0x99,0xfd,0xe6,0x3d,0x45,0x20,0x28,0xd1,0x54,0x21,0xe2,0x96,0x80,0x1f,0x4d,0x7e,0xa2,0x80,0x16,0x25,0xed,0x56,0x2e,0x78,0x64,0x4f,0x41,0x40,0xca,0xb4,0xa7,0x3f,0x85,0x20,0x00,0x7e,0xb4,0xaa,0x68,0x00,0x34,0x94,0x00,0xb9,0xe2,0x9b,0x40,0x84,0xc9,0x1c,0x8a,0x59,0x33,0xdd,0xc1,0xfa,0x1a,0x43,0x1b,0x45,0x00,0x25,0x23,0x50,0x03,0x29,0xc2,0xa8,0x09,0xe1,0xff,0x00,0x5a,0x9f,0x5a,0x9a,0xe7,0xfd,0x51,0xa9,0x01,0x0f,0x54,0x3f,0x4a,0x95,0xb8,0x34,0x0c,0x8a,0x7e,0x26,0x85,0xbd,0x0e,0x29,0xd1,0x7c,0xb7,0x5f,0x89,0x14,0x08,0xa5,0x45,0x50,0x0e,0x14,0xea,0x04,0x3c,0x53,0x1b,0xef,0xd0,0x04,0xd6,0xe3,0x91,0x4b,0x73,0xfe,0xbd,0xe8,0x19,0x5f,0xa0,0xa4,0x3d,0x69,0x00,0xea,0x4a,0x00,0x33,0x4b,0x9c,0x50,0x01,0x49,0x40,0x85,0x5d,0xb9,0xf9,0xba,0x7a,0xd4,0x65,0xbd,0x28,0x18,0xd0,0x71,0x4e,0xa0,0x02,0x90,0xf4,0xa0,0x06,0xd3,0x85,0x00,0x48,0x0e,0x18,0x1f,0x7a,0xb7,0x2f,0x20,0xd2,0x02,0x1c,0xe6,0xdd,0x4f,0xb5,0x58,0x93,0xa5,0x30,0x21,0xbb,0xff,0x00,0x8f,0x7c,0xfa,0x11,0x4b,0x9f,0xf4,0x8c,0xfb,0x83,0x48,0x0a,0x74,0xb5,0x42,0x1d,0x4e,0x14,0x08,0x78,0xa6,0x1f,0xf5,0x94,0x0c,0xb9,0x66,0x2a,0x3b,0xd1,0xfb,0xdf,0xaa,0xd2,0x28,0xae,0x69,0x9d,0xa8,0x10,0x9d,0xe9,0x73,0x40,0x09,0x9a,0x5a,0
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
void app_main(void)
{
    esp_err_t ret;

    // Initialize NVS.
    ret = nvs_flash_init();
    if (ret == ESP_ERR_NVS_NO_FREE_PAGES || ret == ESP_ERR_NVS_NEW_VERSION_FOUND) {
        ESP_ERROR_CHECK(nvs_flash_erase());
        ret = nvs_flash_init();
    }
    ESP_ERROR_CHECK( ret );

    ESP_ERROR_CHECK(esp_bt_controller_mem_release(ESP_BT_MODE_CLASSIC_BT));

    esp_bt_controller_config_t bt_cfg = BT_CONTROLLER_INIT_CONFIG_DEFAULT();
    ret = esp_bt_controller_init(&bt_cfg);
    if (ret) {
        ESP_LOGE(GATTS_TAG, "%s initialize controller failed", __func__);
        return;
    }

    ret = esp_bt_controller_enable(ESP_BT_MODE_BLE);
    if (ret) {
        ESP_LOGE(GATTS_TAG, "%s enable controller failed", __func__);
        return;
    }

    ret = esp_bluedroid_init();
    if (ret) {
        ESP_LOGE(GATTS_TAG, "%s init bluetooth failed", __func__);
        return;
    }
    ret = esp_bluedroid_enable();
    if (ret) {
        ESP_LOGE(GATTS_TAG, "%s enable bluetooth failed", __func__);
        return;
    }

    ret = esp_ble_gatts_register_callback(gatts_event_handler);
    if (ret){
        ESP_LOGE(GATTS_TAG, "gatts register error, error code = %x", ret);
        return;
    }
    ret = esp_ble_gap_register_callback(gap_event_handler);
    if (ret){
        ESP_LOGE(GATTS_TAG, "gap register error, error code = %x", ret);
        return;
    }
    ret = esp_ble_gatts_app_register(PROFILE_A_APP_ID);
    if (ret){
        ESP_LOGE(GATTS_TAG, "gatts app register error, error code = %x", ret);
        return;
    }

    esp_err_t local_mtu_ret = esp_ble_gatt_set_local_mtu(517);
    if (local_mtu_ret){
        ESP_LOGE(GATTS_TAG, "set local  MTU failed, error code = %x", local_mtu_ret);
    }

    // init camera
    if(ESP_OK != init_camera()) {
        return;
    }

    // init picture packet
    ret = pic_packet_init(&pic_packet, packetdata, sizeof(packetdata));
    if(ESP_OK != ret) {
        ESP_LOGE(GATTS_TAG, "picture packet init failed, error code = %x", ret);
	    return;
    }

    // ini the key input
    ret = key_input_init();
    if(ESP_OK != ret) {
        ESP_LOGE(GATTS_TAG, "key input init failed, error code = %x", ret);
	    return;
    }
    xTaskCreate(key_input_task, "key_input_task", 2048, NULL, 10, NULL);

    // init system led control
    gpio_reset_pin(LED_RED);
    gpio_set_direction(LED_RED, GPIO_MODE_OUTPUT);    
    gpio_reset_pin(LED_GREEN);
    gpio_set_direction(LED_GREEN, GPIO_MODE_OUTPUT);    
    gpio_reset_pin(LED_BLUE);
    gpio_set_direction(LED_BLUE, GPIO_MODE_OUTPUT);    
    gpio_set_level(LED_RED, 1); 
    gpio_set_level(LED_GREEN, 1); 
    gpio_set_level(LED_BLUE, 1); 
    xTaskCreate(led_ctrl_task, "led_ctrl_task", 4096, NULL, 10, NULL);

    // init system charge status
    gpio_reset_pin(1);
    gpio_set_direction(1, GPIO_MODE_INPUT);    
    gpio_set_pull_mode(1, GPIO_PULLUP_ONLY);

#if (CONFIG_EXAMPLE_GATTS_NOTIFY_THROUGHPUT)
    // The task is only created on the CPU core that Bluetooth is working on,
    // preventing the sending task from using the un-updated Bluetooth state on another CPU.
    xTaskCreatePinnedToCore(&throughput_server_task, "throughput_server_task", 4096, NULL, 15, NULL, BLUETOOTH_TASK_PINNED_TO_CORE);
#endif

    // init the battery
    ret = battery_init();
    if(ESP_OK != ret) {
        ESP_LOGE(GATTS_TAG, "battery init failed, error code = %x", ret);
    }

#if (CONFIG_EXAMPLE_GATTC_WRITE_THROUGHPUT)
    xTaskCreatePinnedToCore(&throughput_cal_task, "throughput_cal_task", 4096, NULL, 14, NULL, BLUETOOTH_TASK_PINNED_TO_CORE);
#endif

#if (CONFIG_EXAMPLE_GATTS_NOTIFY_THROUGHPUT)
    gatts_semaphore = xSemaphoreCreateBinary();
    if (!gatts_semaphore) {
        ESP_LOGE(GATTS_TAG, "%s, init fail, the gatts semaphore create fail.", __func__);
        return;
    }
#endif /* #if (CONFIG_EXAMPLE_GATTS_NOTIFY_THROUGHPUT) */
    return;
}

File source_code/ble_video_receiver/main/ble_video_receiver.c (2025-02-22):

/* SPI Master example

   This example code is in the Public Domain (or CC0 licensed, at your option.)

   Unless required by applicable law or agreed to in writing, this
   software is distributed on an "AS IS" BASIS, WITHOUT WARRANTIES OR
   CONDITIONS OF ANY KIND, either express or implied.
*/
#include <stdio.h>
#include <stdlib.h>
#include <string.h>
#include <inttypes.h>
#include "freertos/FreeRTOS.h"
#include "freertos/task.h"
#include "esp_system.h"
#include "driver/spi_master.h"
#include "driver/gpio.h"
#include "esp_timer.h"
#include "esp_log.h"

#include "ble_client.h"
#include "decode_image.h"
#include "ble_video_receiver.h"
#include "battery_icon.h"
#include "key_input.h"

#define BLE_VIDEO_REV "ble_video_rev"

extern QueueHandle_t gpio_evt_queue;

uint8_t jpeg_data[10 * 1024];

Frame_data frame_data = {
	.data = jpeg_data,
	.length = 0,
	.data_ready = false,
};

/*
 This code displays some fancy graphics on the 320x240 LCD on an ESP-WROVER_KIT board.
 This example demonstrates the use of both spi_device_transmit as well as
 spi_device_queue_trans/spi_device_get_trans_result and pre-transmit callbacks.

 Some info about the ILI9341/ST7789V: It has an C/D line, which is connected to a GPIO here. It expects this
 line to be low for a command and high for data. We use a pre-transmit callback here to control that
 line: every transaction has as the user-definable argument the needed state of the D/C line and just
 before the transaction is sent, the callback will set this line to the correct state.
*/

//////////////////////////////////////////////////////////////////////////////////////////////////////////
////////////// Please update the following configuration according to your HardWare spec /////////////////
//////////////////////////////////////////////////////////////////////////////////////////////////////////
#define LCD_HOST    SPI2_HOST

#define PIN_NUM_MISO -1 
#define PIN_NUM_MOSI 40
#define PIN_NUM_CLK  41
#define PIN_NUM_CS   38

#define PIN_NUM_DC   39
#define PIN_NUM_RST  36 
#define PIN_NUM_BCKL 42

#define LCD_BK_LIGHT_ON_LEVEL  1 
#define LCD_BK_LIGHT_OFF_LEVEL  0 

//To speed up transfers, every SPI transfer sends a bunch of lines. This define specifies how many. More means more memory use,
//but less overhead for setting up / finishing transfers. Make sure 240 is dividable by this.
#define PARALLEL_LINES 32 

spi_device_handle_t spi;
/*
 The LCD needs a bunch of command/argument values to be initialized. They are stored in this struct.
*/
typedef struct {
    uint8_t cmd;
    uint8_t data[16];
    uint8_t databytes; //No of data in data; bit 7 = delay after set; 0xFF = end of cmds.
} lcd_init_cmd_t;

typedef enum {
    LCD_TYPE_ILI = 1,
    LCD_TYPE_ST,
    LCD_TYPE_MAX,
} type_lcd_t;

//Place data into DRAM. Constant data gets placed into DROM by default, which is not accessible by DMA.
DRAM_ATTR static const lcd_init_cmd_t st_init_cmds[] = {
    /* Porch Setting */
    {0xB2, {0x0c, 0x0c, 0x00, 0x33, 0x33}, 5},
    /* Display Inversion Off */
    {0x20, {0x00}, 0x80},
    /* Gate Control, Vgh=13.65V, Vgl=-10.43V */
    {0xB7, {0x56}, 1},
    /* VCOM Setting, VCOM=1.175V */
    {0xBB, {0x18}, 1},
    /* LCM Control, XOR: BGR, MX, MH */
    {0xC0, {0x2C}, 1},
    /* VDV and VRH Command Enable, enable=1 */
    {0xC2, {0x01}, 1},
    /* VRH Set, Vap=4.4+... */
    {0xC3, {0x1f}, 1},
    /* VDV Set, VDV=0 */
    {0xC4, {0x20}, 1},
    /* Frame Rate Control, 60Hz, inversion=0 */
    {0xC6, {0x0f}, 1},
    /* Power Control 1, AVDD=6.8V, AVCL=-4.8V, VDDS=2.3V */
    {0xD0, {0xA6, 0xA1}, 2},
    /* Positive Voltage Gamma Control */
    {0xE0, {0xD0, 0x0d, 0x14, 0x0b, 0x0b, 0x07, 0x3a, 0x44, 0x50, 0x08, 0x13, 0x13, 0x2d, 0x32}, 14},
    /* Negative Voltage Gamma Control */
    {0xE1, {0xD0, 0x0d, 0x14, 0x0b, 0x0b, 0x07, 0x3a, 0x44, 0x50, 0x08, 0x13, 0x13, 0x2d, 0x32}, 14},
    /* Memory Data Access Control, MX=MV=1, MY=ML=MH=0, RGB=0 */
    {0x36, {0x00}, 1},
    /* Interface Pixel Format, 16bits/pixel for RGB/MCU interface */
    {0x3A, {0x55}, 1},
    {0xe7, {0x00}, 1},
    /* Sleep Out */
    {0x11, {0}, 0x80},
    /* Display inversion on */
    {0x21, {0}, 0x80},
    /* Display On */
    {0x29, {0}, 0x80},
    {0, {0}, 0xff}
};

DRAM_ATTR static const lcd_init_cmd_t ili_init_cmds[] = {
    /* Power contorl B, power control = 0, DC_ENA = 1 */
    {0xCF, {0x00, 0x83, 0X30}, 3},
    /* Power on sequence control,
     * cp1 keeps 1 frame, 1st frame enable
     * vcl = 0, ddvdh=3, vgh=1, vgl=2
     * DDVDH_ENH=1
     */
    {0xED, {0x64, 0x03, 0X12, 0X81}, 4},
    /* Driver timing control A,
     * non-overlap=default +1
     * EQ=default - 1, CR=default
     * pre-charge=default - 1
     */
    {0xE8, {0x85, 0x01, 0x79}, 3},
    /* Power control A, Vcore=1.6V, DDVDH=5.6V */
    {0xCB, {0x39, 0x2C, 0x00, 0x34, 0x02}, 5},
    /* Pump ratio control, DDVDH=2xVCl */
    {0xF7, {0x20}, 1},
    /* Driver timing control, all=0 unit */
    {0xEA, {0x00, 0x00}, 2},
    /* Power control 1, GVDD=4.75V */
    {0xC0, {0x26}, 1},
    /* Power control 2, DDVDH=VCl*2, VGH=VCl*7, VGL=-VCl*3 */
    {0xC1, {0x11}, 1},
    /* VCOM control 1, VCOMH=4.025V, VCOML=-0.950V */
    {0xC5, {0x35, 0x3E}, 2},
    /* VCOM control 2, VCOMH=VMH-2, VCOML=VML-2 */
    {0xC7, {0xBE}, 1},
    /* Memory access contorl, MX=MY=0, MV=1, ML=0, BGR=1, MH=0 */
    {0x36, {0x28}, 1},
    /* Pixel format, 16bits/pixel for RGB/MCU interface */
    {0x3A, {0x55}, 1},
    /* Frame rate control, f=fosc, 70Hz fps */
    {0xB1, {0x00, 0x1B}, 2},
    /* Enable 3G, disabled */
    {0xF2, {0x08}, 1},
    /* Gamma set, curve 1 */
    {0x26, {0x01}, 1},
    /* Positive gamma correction */
    {0xE0, {0x1F, 0x1A, 0x18, 0x0A, 0x0F, 0x06, 0x45, 0X87, 0x32, 0x0A, 0x07, 0x02, 0x07, 0x05, 0x00}, 15},
    /* Negative gamma correction */
    {0XE1, {0x00, 0x25, 0x27, 0x05, 0x10, 0x09, 0x3A, 0x78, 0x4D, 0x05, 0x18, 0x0D, 0x38, 0x3A, 0x1F}, 15},
    /* Column address set, SC=0, EC=0xEF */
    {0x2A, {0x00, 0x00, 0x00, 0xEF}, 4},
    /* Page address set, SP=0, EP=0x013F */
    {0x2B, {0x00, 0x00, 0x01, 0x3f}, 4},
    /* Memory write */
    {0x2C, {0}, 0},
    /* Entry mode set, Low vol detect disabled, normal display */
    {0xB7, {0x07}, 1},
    /* Display function control */
    {0xB6, {0x0A, 0x82, 0x27, 0x00}, 4},
    /* Sleep out */
    {0x11, {0}, 0x80},
    /* Display on */
    {0x29, {0}, 0x80},
    {0, {0}, 0xff},
};
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

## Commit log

2024-08-15 upload demo code for bluetooth device Which can work with https://github.com/sidianneng/bluetooth-video-transmission/blob/main/tools/video_receiver.html
2024-10-18 upload 3d modules
    [ble-video-camera-v62.stl, receiver-v3.stl, sender-back-v13.stl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]
2024-10-26 upload datesheet of usb-to-uart chip
2024-10-26 upload datasheet of charge chip(TP4055)
2024-11-05 init commit for ble video receiver with LCD driver and jpg display ok
2024-11-07 fix the picture display in loop
    [ble_video_receiver.c]
2024-12-02 add camera code into video sender
2024-12-29 display battery icon is OK
2025-01-01 Revert "add dual buffer to speed up the video transfer rate(now fps is 13)"
    This reverts commit c2deb235dd678eb37dc98bc414e787a9d2439b93.
    [ble_video_receiver.c]
2025-01-02 fix the lcd init noise
    [ble_video_receiver.c]
2025-01-02 add battery icon of differen status
2025-01-02 optimize the position of battery icon on lcd
2025-02-07 add app led control
2025-02-18 update gpios for camera and leds
2025-02-22 update gpio of leds
2025-02-22 add gpio to get charge status(low means in charging, high means charge is finished)
2025-02-22 enable adc function on GPIO14 to get battery voltage
2025-02-22 update battery capacity volgate
2025-02-22 remove useless log of battery
2025-02-22 update battery capacity voltage
2025-02-22 update led control logic 1 charging, the led always turns on with different color to show the battery capacity 2 when the button pressed but not charging, the led blink with differen color to show ba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
2025-02-22 add battery icon of charging
2025-02-22 update icon display and charge status detect
2025-02-22 upodate 3d module to the latest
    [ble-video-camera-v62.stl, ble-video-camera-v88.stl, receiver-v3.stl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]
2025-02-22 upload schematic pcb gerber and bom for sender and receiver
